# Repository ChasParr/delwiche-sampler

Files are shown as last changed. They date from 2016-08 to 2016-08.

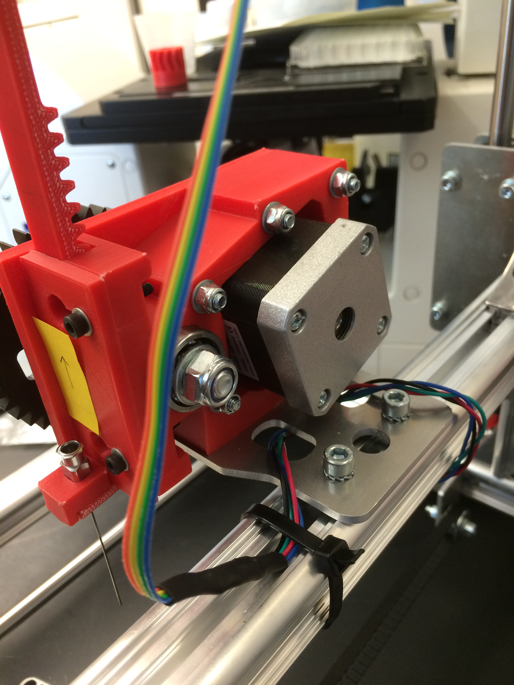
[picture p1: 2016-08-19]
pictures/IMG_1877.JPG

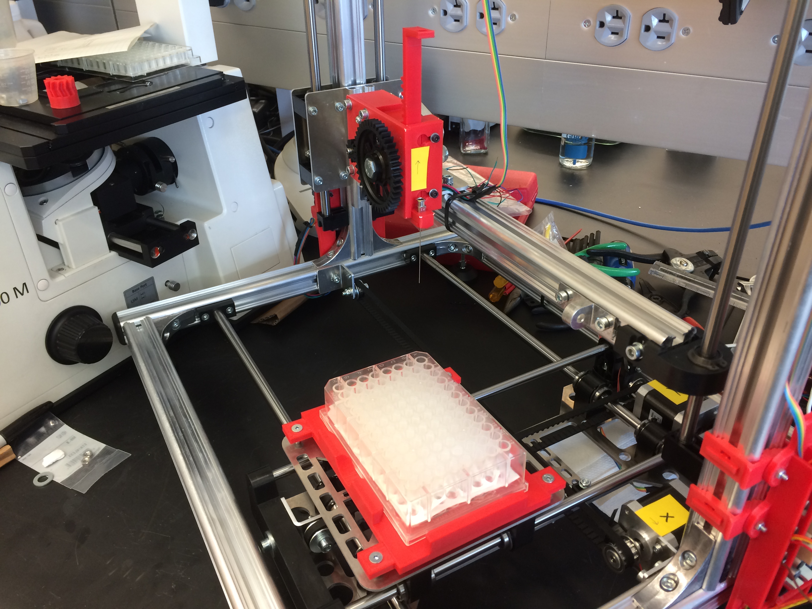
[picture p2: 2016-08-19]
pictures/IMG_1880[2].JPG

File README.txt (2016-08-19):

delwiche-sampler

This project converts a Velleman K8200 or 3Drag 3d printer into an autosampler.

Instructions for assembling the printer can be found here: http://www.k8200.eu/manual/building/
For this project do not assemble the coil support, heated bed, or extruder.

The parts used to replace the extruder can be 3d printed, the OpenSCAD files are in the "3D parts" folder.

Photos of the assembled extruder replacement can be found in the "pictures" folder.

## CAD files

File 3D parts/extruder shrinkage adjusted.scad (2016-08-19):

// Public Domain Parametric Involute Spur Gear (and involute helical gear and involute rack)
// version 1.1
// by Leemon Baird, 2011, Leemon@Leemon.com
//http://www.thingiverse.com/thing:5505

/*
this assemblage is intended to replace the extruder of a 
Velleman K8200 or 3Drag 3D printer.

most of the non-printable parts are the same, and used the same
as in the original extruder, except the following:
4x m3x12mm screws and washers (for attaching the motor)
2x m3x20mm bolts, washers, and nuts (for attaching the rack guide)
1x 8mmx60mm hex bolt (to replace the hobbed bolt)
*/

n1 = 12; //red gear number of teeth
n5 = 15;  //gray rack
mm_per_tooth = 5; //all meshing gears need the same mm_per_tooth (and the same pressure_angle)
pressure_angle=20;
thickness    = 6;   // 1/2 width of gear and rack
hole         = 8.2;   // center hole of gear
height       = 7.5;
angle        = 15;
animLength   = 11;
extensionBot = 30;
extensionTop = 30;
echo("outer radius: ", outer_radius(mm_per_tooth, n1));

d1  = pitch_radius(mm_per_tooth,n1);
rackOffset = mm_per_tooth / 3.1415926; 

// stand upright
rotate([0, -90, 0]){

// red gear
   
rotate([0,0, $t*360/n1 * animLength]){
    color([1.00,0.75,0.75]){
        gear(mm_per_tooth,n1,thickness,hole, angle, 0, pressure_angle);
        mirror([0, 0, 1])
            gear(mm_per_tooth,n1,thickness,hole, angle, 0, pressure_angle);
        render()
        translate([0, 0, -thickness - 9])
        difference(){
            cylinder(r = outer_radius(mm_per_tooth, n1), h = 9);
            cylinder(r = hole / 2, h = 9, $fn = 20);
            translate([0, 0, 4.5])
            rotate([90, 0, 0])
            cylinder(r = 1.5, h = outer_radius(mm_per_tooth, n1), $fn = 10);
        }
    }
}


// rack
translate([(-floor(n5/2)-floor(n1/2)+$t*animLength+n1/2-n5/2 + 2)*mm_per_tooth,-d1-0,0]){
    color([0.75,0.75,0.75]){
        rack(mm_per_tooth,n5,thickness,height, angle, pressure_angle);
        mirror([0, 0, 1])
            rack(mm_per_tooth,n5,thickness,height, angle, pressure_angle);
    }
    
    // bottom extension 
    translate([-extensionBot - mm_per_tooth/4, rackOffset - height, 0]){
        render() difference(){
            translate([0, 0, -thickness]){
                cube([extensionBot, height - rackOffset * 2, thickness * 2]); // shaft
                translate([0, -height * 1.5 - 5, 0])
                    cube([5, height * 1.5 + 5, thickness * 2]); // foot
            }
            translate([0, -height * .7 - 5, 0])
                rotate([0, 90, 0])
                    cylinder(h = 5, r = 3, $fn = 16);// hole
            
            translate([-1, -height * 1.5 - 5, -thickness - 1]){ // foot bevels
                // bottom
                rotate([0, -angle, 0])
                    cube([2.5, height * 2.5 + 5, thickness*1.2]);
                translate([0, 0, thickness * 2 + 2])
                    rotate([0, angle + 90, 0])
                        cube([thickness*1.2, height * 2.5 + 5, 2.5]);
                // top
                translate([6, 0, 0]){
                    rotate([0, -angle, 0])
                        cube([2.5, 8 * 1.5, (thickness+1)/cos(15)]);
                    translate([0, 0, thickness * 2 + 2])
                        rotate([0, angle + 90, 0])
                            cube([(thickness+1)/cos(15), 8*1.5, 2.5]);
                }
            }
        }
        // needle for reference
        //translate([25,-height * .7 - 5, 0])
            //needle();
    }
    
    // top extension
    translate([mm_per_tooth * n5 - mm_per_tooth / 4, rackOffset - height, 0]){
        translate([0, 0, -thickness])
            cube([extensionTop, height - rackOffset * 2, thickness * 2]); // shaft
        translate([extensionTop - 4, 0, 0]){
            render() difference(){
                translate([0, -height * 1.5 - 5, -thickness])
                    cube([4, height * 1.5 + 5, thickness * 2]); // foot
                translate([0, -height * .7 - 5, 0])
                    rotate([0, 90, 0])
                        cylinder(h = 5, r = 4);         // hole
            }
        }
    }
    
}

render(){
    translate([0, 0, 11.5 + .1])
        rotate([0, 180, -90]){
            translate([0, 0, -.1])
                newPlate();
            centerBlock();
            translate([-.1, 0, 0])
                rackGuide();
        }
}

}


// for printing
/*
render() newPlate();
translate([-28, -39, 0])
    cylinder(r = 7, h = 1);
translate([-28, 37, 0])
    cylinder(r = 7, h = 1);
translate([78, -39, 0])
    cylinder(r = 7, h = 1);
translate([78, 37, 0])
    cylinder(r = 7, h = 1);
*/
/*
render() rotate([0, 90, 0])
    translate([16, 0, 0])
        rackGuide();
translate([-2.3, -5, 0])
    cylinder(r = 3.5, h = 1, $fn = 20);
translate([-2.3, 4.2, 0])
    cylinder(r = 3.5, h = 1, $fn = 20);
translate([-2.3, -27.8, 0])
    cylinder(r = 3.5, h = 1, $fn = 20);
translate([-2.3, 27.2, 0])
    cylinder(r = 3.5, h = 1, $fn = 20);
translate([3, 35, 0])
    cylinder(r = 3.5, h = 1, $fn = 20);
translate([3, -37, 0])
    cylinder(r = 3.5, h = 1, $fn = 20);
translate([34.8, 35, 0])
    cylinder(r = 3.5, h = 1, $fn = 20);
translate([34.8, -37, 0])
    cylinder(r = 3.5, h = 1, $fn = 20);
*/
/*
render() translate([0, 0, 33])
    rotate([0, 180, 0])
        centerBlock();
translate([19, 35, 0])
    cylinder(r = 5, h = 1);
translate([19, -37, 0])
    cylinder(r = 5, h = 1);
translate([0, 35, 0])
    cylinder(r = 5, h = 1);
translate([-.5, -37, 0])
    cylinder(r = 5, h = 1);
translate([-30, 35, 0])
    cylinder(r = 5, h = 1);
translate([-35, -39, 0])
    cylinder(r = 5, h = 1);
translate([-77, 35, 0])
    cylinder(r = 5, h = 1);
translate([-77, -37, 0])
    cylinder(r = 5, h = 1);
*/
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

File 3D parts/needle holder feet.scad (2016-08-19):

thickness = 8;
angle = 15;
space = .4;
$fn = 17;

render() difference(){
    union(){
        cylinder(r = 2.85, h = thickness + 3);
        difference(){
            union(){
                translate([-6, -5.5, 0])
                    cube([12, 12.25, thickness]);
                translate([-6, 6.5, 0])
                    cube([12, 3, thickness + 3]);
            }
            translate([0, -5.75, thickness])
                rotate([0, angle, 0])
                    cube([12, 12.25, thickness]);
            translate([0, -5.75, thickness])
                rotate([0, -angle, 0])
                    translate([-12, 0, 0])
                        cube([12, 12.25, thickness]);
            translate([0, 6.5, thickness + 3])
                rotate([0, angle, 0])
                    cube([12, 3, thickness]);
            translate([0, 6.5, thickness + 3])
                rotate([0, -angle, 0])
                    translate([-12, 0, 0])
                        cube([12, 3, thickness]);
            
        }
        
    }
    
    cylinder(r = .3 + space, h = thickness + 3);
    difference(){
        intersection(){
            minkowski(){
            cube([3.8, 3, 9], true);
            cylinder(h = 1, r=1.5 + space);
            }
        }
    }
    translate([0, 0, 5]){
    cylinder(r1 = 2.3 + space, r2 = 1.5 + space, h = 2);
        translate([0, 0, 2]){
            cylinder(h = 1.1, r1 = 1.5 + space, r2 = 1.5 + space);
            translate([0, 0, 1.1]) 
                cylinder(h = 1.7, r1 = 1.5 + space, r2 = 1.1 + space);
            cylinder(h = 3, r1 = 1.1 + space, r2 = 1 + space);
        }
    }
}

//feet
translate([-8, -8, 0])
    cylinder(r = 4, h = 1);
translate([-8, 12, 0])
    cylinder(r = 4, h = 1);
translate([8, -8, 0])
    cylinder(r = 4, h = 1);
translate([8, 12, 0])
    cylinder(r = 4, h = 1);

//translate([0, 0, -8.])
//    rotate([0, 90, 0])
//        needle();

module needle(){
$fn = 20;
    rotate([0, -90, 0]){
        render() difference(){
            union(){
                translate([0, 0, .4])
                minkowski(){
                    cube([3.8, 3, .8], true);
                    cylinder(h = .1, r=1.5);
                }
                cylinder(h = 5, r=2.8);    
                translate([0, 0, 9]){
                    difference(){
                        intersection(){
                            minkowski(){
                            cube([3.8, 3, 10], true);
                                
                            cylinder(h = 1, r=1.5);
                            }
                            translate([0, 0, 2])
                            sphere(r = 7, $fn = 40);
                        }
                        translate([0, 0, 9]){
                            rotate_extrude(angle = 360){
                                translate([5.4, 0, 0])
                                    scale([.8, 1.1, 1])
                                        circle(r = 6, $fn = 40);
                            }
                        }
                    }
                }
                translate([0, 0, 15]){
                        cylinder(h = 1.1, r1 = 1.5, r2 = 1.5);
                        translate([0, 0, 1.1]) 
                            cylinder(h = 1.7, r1 = 1.5, r2 = 1.1);
                        cylinder(h = 3, r1 = 1.1, r2 = 1);
                    }
                //needle
                cylinder(h = 70, r = .3);
            }
            translate([-7, 0, 0]){
                cylinder(h = 15, r = 3.9, $fn = 40);
            }
            translate([7, 0, 0]){
                cylinder(h = 15, r = 3.9, $fn = 40);
            }
            cylinder(h = 7, r = 2.1);
            translate([0, 0, 7]){
                cylinder(h = 2, r1 = 2.1, r2 = .5);
                translate([0, 0, 2])
                    cylinder(h = 5, r1 = .5, r2 = .25);
            }
            cylinder(h = 70, r = .2);
        }
    }
}

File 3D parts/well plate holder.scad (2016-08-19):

$fn = 24;
// parameters (mm)

baseLength = 127.76;            // plate length
baseWidth = 85.48;              // plate width
room = .17;

length = baseLength + room*2;   // indentation length
width = baseWidth + room*2;     // indentation width
height = 10;                    // indentation height


// for specific max dimensions: 
// marginX = ([desiredLength] - length) / 2;
// marginY = ([desiredWidth] - width) / 2;
// marginZ = ([desiredHeight] - height);
marginX = 10;            // wall thickness (length)
marginY = 10;            // wall thickness (width)
marginZ = 6;             // base thickness (height)

// to remove a strut set it to 0
lipWidth = 10;          // lip width
strutA = 15;            // - strut width
strutB = 12;            // | strut width
strutX = 10;            // X struts width
strutZ = 5;             // strut thickness

screwMargin = 8;
screwRad = 2;
screwHeadRad = 4;
screwHeadDepth = 2;
screwDistX = 122;
screwDistY = 122;
plateThickness = 5;

// calculations
fullLength = length + marginX * 2;  // full length
fullWidth = width + marginY * 2;    // full width
fullHeight = height + marginZ;    // full height
cutoutLength = length - lipWidth * 2;  // cutout length
cutoutWidth = width - lipWidth * 2;    // cutout width
// diagonal strut length
strutLength = sqrt(cutoutLength*cutoutLength + cutoutWidth*cutoutWidth);
// screw plate dimensions
plateX = screwMargin * 2;
plateY = (screwMargin + (screwDistY - fullWidth) / 2);
offsetX = (screwMargin + (screwDistX - fullLength) / 2);


// Frame
translate([offsetX, plateY, 0]){
    // well plate (remove for printing)
    /*
    translate([marginX + room, marginY + room, marginZ]){
        cube([127.76, 85.48, 5.5]);
        translate([1.5, 1.5, 0]){
            cube([124.76, 82.48, 14.1]); 
        }
    }
    */
    render() difference(){
        // outside block
        cube([fullLength, fullWidth, fullHeight]);
        // indentation
        translate([marginX, marginY, marginZ]){
            cube([length, width, height]);
        }
        // corner cuts
        translate([0, 0, marginZ]){
            rotate([0, 0, 45]){
                translate([-10, -20, 0]){
                    cube([60, 30, height + 2]);
                }
            }
            cube([33.3, 19.2, height + 2]);
            translate([0, fullWidth, 0]){
                rotate([0, 0, -45]){
                    translate([-10, -10, 0]){
                        cube([60, 30, height + 2]);
                    }
                }
                translate([0, -19.2, 0])
                cube([33.3, 19.2, height + 2]);
            }
            translate([fullLength, fullWidth, 0]){
                rotate([0, 0, 225]){
                    translate([-10, -20, 0]){
                        cube([60, 30, height + 2]);
                    }
                }
                translate([-33.3, -19.2, 0])
                cube([33.3, 19.2, height + 2]);
            }
            translate([fullLength, 0, 0]){
                rotate([0, 0, -225]){
                    translate([-10, -10, 0]){
                        cube([60, 30, height + 2]);
                    }
                }
                translate([-33.3, 0, 0])
                cube([33.3, 19.2, height + 2]);
            }
        }
        // cutout bottom
        translate([marginX + lipWidth, marginY + lipWidth, 0]){
            cube([cutoutLength, cutoutWidth, marginZ]);
        }
        // side holes
        translate([fullLength / 2, 0, fullHeight + 2]){
            rotate([-90, 0, 0]){
            cylinder(h = marginY, r = height + 2);
            }
        }
        translate([fullLength / 2, fullWidth, fullHeight + 2]){
            rotate([90, 0, 0]){
            cylinder(h = marginY, r = height + 2);
            }
        }
        // Bevel
        translate([fullLength / 2, fullWidth / 2, fullHeight+ height/2]){
            intersection(){
                rotate([45, 0, 0]){
                    // along x
                    cube([fullLength, fullWidth/sqrt(2), fullWidth/sqrt(2)], true);
                }
                rotate([0, 45, 0]){
                    // along y
                    cube([fullLength/sqrt(2), fullWidth, fullLength/sqrt(2)], true);
                }
                cube([fullLength, fullWidth, height*2], true);
            }
        }
    }
    
    // Struts
    
    // strutA
    // [   ]
    // [---]
    // [   ].
    translate([(fullLength - strutA) / 2, marginY + lipWidth, 0]){
        cube([strutA, cutoutWidth, strutZ]);
    }

    // strutB
    // [ | ]
    // [ | ]
    // [ | ].
    translate([marginX + lipWidth, (fullWidth - strutB) / 2, 0]){
        cube([cutoutLength, strutB, strutZ]);
    }

    // strutX
    // [\  ]
    // [ \ ]
    // [  \].
    translate([(marginX + lipWidth), (marginY + lipWidth), 0]){
        rotate([0, 0, atan2(cutoutWidth, cutoutLength)]){
            translate([0, -strutX / 2, 0]){
                cube([strutLength, strutX, strutZ]);
            }
        }
    }

    // strutX
    // [  /]
    // [ / ]
    // [/  ].
    translate([(marginX + lipWidth), marginY + width - lipWidth, 0]){
        rotate([0, 0, atan2(-cutoutWidth, cutoutLength)]){
            translate([0, -strutX / 2, 0]){
                cube([strutLength, strutX, strutZ]);
            }
        }
    }
    translate([marginX + lipWidth + cutoutLength, marginY + lipWidth, 0]){
        rotate([0, 0, 45]){
            translate([-10, -10, 0]){
                cube([20,20,marginZ]);
            }
        }
    }
    translate([marginX + lipWidth + cutoutLength, marginY + lipWidth + cutoutWidth, 0]){
        rotate([0, 0, 45]){
            translate([-10, -10, 0]){
                cube([20,20,marginZ]);
            }
        }
    }
}

// Screw plates
render() difference(){
    cube([plateX, plateY, plateThickness]);
    translate([screwMargin, screwMargin, 0]){
        cylinder(h = plateThickness, r = screwRad);
        translate([0, 0, plateThickness - screwHeadDepth]){
            cylinder(h = screwHeadDepth, r1 = screwRad, r2 = screwHeadRad);
        }
    }
}
render() difference(){
    translate([screwDistX, 0, 0]){
        cube([plateX, plateY, plateThickness]);
    }
    translate([screwMargin + screwDistX, screwMargin, 0]){
       cylinder(h = plateThickness, r = screwRad);
       translate([0, 0, plateThickness - screwHeadDepth]){
            cylinder(h = screwHeadDepth, r1 = screwRad, r2 = screwHeadRad);
        }
    } 
}
render() difference(){
    translate([0, plateY + fullWidth, 0]){
        cube([plateX, plateY, plateThickness]);
    }
    translate([screwMargin, screwMargin + screwDistY, 0]){
       cylinder(h = plateThickness, r = screwRad);
       translate([0, 0, plateThickness - screwHeadDepth]){
            cylinder(h = screwHeadDepth, r1 = screwRad, r2 = screwHeadRad);
       }
    }
}
render() difference(){
    translate([screwDistX, plateY + fullWidth, 0]){
        cube([plateX, plateY, plateThickness]);
    }
    translate([screwMargin + screwDistX, screwMargin + screwDistY, 0]){
       cylinder(h = plateThickness, r = screwRad);
       translate([0, 0, plateThickness - screwHeadDepth]){
            cylinder(h = screwHeadDepth, r1 = screwRad, r2 = screwHeadRad);
       }
    }
}

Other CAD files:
3D parts/needle holder.scad

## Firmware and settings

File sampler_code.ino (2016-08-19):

/**
* G-code interpreter for the Delwiche-Sampler project
*   
* Copyright 2016 Chas Parr <cxp2265@rit.edu>
*
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
* Some of the following code is derived from the GcodeCNCDemo project
* http://www.github.com/MarginallyClever/GcodeCNCDemo
*/

/**
 * This sketch allows the sampler to interpret g-code commands sent to it via serial port.
 * 
 * In the Arduino IDE under 'tools' set the board to "Arduino/Genuino Mega or Mega 2560", 
 * and the port to whichever one the Arduino is connected to.
 * 
 * While uploading to the arduino, hold a screwdriver between the prongs on the port labeled "JPROG" 
 * until the upload is complete
 * 
 * The Serial Monitor tool in the IDE can be used to send G-code directly to the machine for testing purposes
 */

//------------------------------------------------------------
// Constants
//------------------------------------------------------------
#define BAUD            (57600)   // communication rate
#define MAX_BUF         (64)      // how long of a message can be stored
#define STEPS_PER_TURN  (200)     // the number of full steps for one revolution of a stepper motor
#define MICROSTEPS      (16)      // the number of microsteps each step is divided into
#define NUM_AXES        (4)       // the number of axes that can be moved along (X, Y, Z, E)
#define MAX_FEEDRATE    (1000000) // the highest speed (no delay between steps)
#define MIN_FEEDRATE    (1)

//------------------------------------------------------------
// Structs
//------------------------------------------------------------
/**
 * Motor struct
 * stores pin locations, motor/axis settings, and positional information
 */
typedef struct {
  int step_pin;       // this pin makes the motor step
  int dir_pin;        // this pin controls the motor direction
  int enable_pin;     // this pin enables the motor
  int switch_pin;     // this pin reads from an end stop if there is one, otherwise set it to -1
  float steps_per_mm; // the number of microsteps it takes to move the axis linearly one mm
  bool invert;        // flips the motor direction
  long pos;           // absolute position in microsteps
  long min_pos;       // minimum position on axis in microsteps (usually 0)
  long max_pos;       // maximum position on axis in microsteps
  int dir;            // set to 1 or -1 when moving, used to increment position
} Motor;

//------------------------------------------------------------
// Vars
//------------------------------------------------------------
Motor motors[NUM_AXES]; // stores the motors
char buffer[MAX_BUF];   // stores command till it hits a ';'
int sofar;              // position in buffer
boolean abs_mode;     
  // absolute mode (true): move commands are given as a position to move to
  // relative mode (false): move commands are given as a distance to move

boolean mm_mode;
  // (true): distances are read as millimeters
  // (false): distances are read as micro steps

// speeds
long fr = 0;            // feed rate
long step_delay;        // the delay between steps, derived from the feed rate

//------------------------------------------------------------
// Methods
//------------------------------------------------------------
/**
 * Set the feedrate (speed motors will move)
 * @input nfr the new speed in steps/second
 */
void set_feedrate(long nfr) {
  if(fr == nfr) return;  // quit if no change

  if(nfr > MAX_FEEDRATE || nfr < MIN_FEEDRATE) {  // don't allow crazy feed rates
    Serial.print(F("New feedrate must be greater than "));
    Serial.print(MIN_FEEDRATE);
    Serial.print(F("steps/s and less than "));
    Serial.print(MAX_FEEDRATE);
    Serial.println(F("steps/s."));
    return;
  }
  step_delay = MAX_FEEDRATE / nfr;  // calculate the delay between steps
  fr = nfr;
}

/**
 * provide positional information
 */
void where() {
  Serial.print("X ");
  Serial.print(motors[0].pos / motors[0].steps_per_mm);
  Serial.print("mm ");
  Serial.print(motors[0].pos);
  Serial.println(" micro steps");
  Serial.print("Y ");
  Serial.print(motors[1].pos / motors[1].steps_per_mm);
  Serial.print("mm ");
  Serial.print(motors[1].pos);
  Serial.println(" micro steps");
  Serial.print("Z ");
  Serial.print(motors[2].pos / motors[2].steps_per_mm);
  Serial.print("mm ");
  Serial.print(motors[2].pos);
  Serial.println(" micro steps");
  Serial.print("E ");
  Serial.print(motors[3].pos / motors[3].steps_per_mm);
  Serial.print("mm ");
  Serial.print(motors[3].pos);
  Serial.println(" micro steps");
  Serial.print("F ");
  Serial.println(fr);
}

/**
 * print helpful info
 */
void help() {
  Serial.println(F("Commands:"));
  Serial.println(F("G00 [X/Y/Z/E(steps or mm)] [F(steps/sec)]; - rapid move"));
  Serial.println(F("G21; - set units to mm"));  
  Serial.println(F("G24; - set units to micro steps"));  
  Serial.println(F("G28; - zero position"));  
  Serial.println(F("G90; - absolute mode"));
  Serial.println(F("G91; - relative mode"));
  Serial.println(F("M17; - enable motors"));
  Serial.println(F("M18; - disable motors"));
  Serial.println(F("M100; - this help message"));
  Serial.println(F("M114; - report position and feedrate"));
  
}

/**
 * set up the motor pins and settings
 */
void motor_setup() {
  // x-axis
  motors[0].step_pin = 54;
  motors[0].dir_pin = 55;
  motors[0].enable_pin = 38;
  motors[0].switch_pin = 3;
  motors[0].steps_per_mm = STEPS_PER_TURN * MICROSTEPS / 50;  // one full revolution moves 50mm
  motors[0].pos = 1;  // ensures it can zero on startup
  motors[0].min_pos = 0;
  motors[0].max_pos = 220 * motors[0].steps_per_mm; // max position is 220mm from zero
  motors[0].invert = true;

  // y-axis
  motors[1].step_pin = 60;
  motors[1].dir_pin = 61;
  motors[1].enable_pin = 56;
  motors[1].switch_pin = 14;
  motors[1].steps_per_mm = STEPS_PER_TURN * MICROSTEPS / 50;  // one full revolution moves 50mm
  motors[1].pos = 1;  // ensures it can zero on startup
  motors[1].min_pos = 0;
  motors[1].max_pos = 200 * motors[1].steps_per_mm; // max position is 200mm from zero
  motors[1].invert = false;

  // z-axis
  motors[2].step_pin = 46;
  motors[2].dir_pin = 48;
  motors[2].enable_pin = 63;
  motors[2].switch_pin = 18;
  motors[2].steps_per_mm = STEPS_PER_TURN * MICROSTEPS / 1.2;  // one full revolution moves 1.2mm
  motors[2].pos = 1;  // ensures it can zero on startup
  motors[2].min_pos = 0;
  motors[2].max_pos = 200 * motors[2].steps_per_mm; // max position is 200mm from zero
  motors[2].invert = false;

  // extruder
  motors[3].step_pin = 26;
  motors[3].dir_pin = 28;
  motors[3].enable_pin = 24;
  motors[3].switch_pin = -1;
  motors[3].steps_per_mm = STEPS_PER_TURN * MICROSTEPS / 14;  // one full revolution moves 14mm
  motors[3].pos = 0;  // prevent it from trying to zero on startup
  motors[3].min_pos = 0;
  motors[3].max_pos = 57 * motors[3].steps_per_mm; // max position is 57mm from zero
  motors[3].invert = true;

  for(int i = 0; i < NUM_AXES; i++) {  
    
    // set up the motor pins
    pinMode(motors[i].step_pin, OUTPUT);
    pinMode(motors[i].dir_pin, OUTPUT);
    pinMode(motors[i].enable_pin, OUTPUT);
    
    // set up the switch pin if there is an endstop
    if (motors[i].switch_pin > 0){
      pinMode(motors[i].switch_pin, INPUT_PULLUP);
    }
  }
}

/**
 * prepare for the next command
 */
void ready() {
  sofar = 0;
  Serial.print(F("> "));
}

/**
 * Look for character /code/ in the buffer and read the float that immediately follows it.
 * @return the value found.  If nothing is found, /val/ is returned.
 * @input code the character to look for.
 * @input val the return value if /code/ is not found.
 */
float parseNumber(char code, float val) {
  char *ptr = buffer;
  while(ptr && *ptr && ptr < buffer + sofar) {
    if(*ptr == code) {
      return atof(ptr + 1);
    }
    ptr = strchr(ptr, ' ') + 1;
  }
  return val;
}

/**
 * Read the input buffer and find any recognized commands.  One G or M command per line.
 */
void processCommand() {
  int cmd = parseNumber('G', -1);
  switch(cmd) {
    case 0:  // rapid move command
      set_feedrate(parseNumber('F', fr));
      
      // read positions into rapid_move
      // if a position is unspecified it defaults to no movement
      // in mm mode the input is multiplied by 100 to preserve decimals
      if (!abs_mode){
        if (mm_mode){
          rapid_move( parseNumber('X', 0) * 100,
                      parseNumber('Y', 0) * 100,
                      parseNumber('Z', 0) * 100,
                      parseNumber('E', 0) * 100);
        } else{
          rapid_move( parseNumber('X', 0),
                      parseNumber('Y', 0),
                      parseNumber('Z', 0),
                      parseNumber('E', 0) );
        }
      } else {
        if (mm_mode){
          rapid_move( parseNumber('X', motors[0].pos / motors[0].steps_per_mm) * 100,
                      parseNumber('Y', motors[1].pos / motors[1].steps_per_mm) * 100,
                      parseNumber('Z', motors[2].pos / motors[2].steps_per_mm) * 100,
                      parseNumber('E', motors[3].pos / motors[3].steps_per_mm) * 100);
          
        } else{
          rapid_move( parseNumber('X', motors[0].pos),
                      parseNumber('Y', motors[1].pos),
                      parseNumber('Z', motors[2].pos),
                      parseNumber('E', motors[3].pos) );
        }
      }
      break;
    case 21:  // set units to mm
      mm_mode = true;
      Serial.println("input set to mm"); 
      break;
    case 24:  // set units to micro steps
      mm_mode = false;
      Serial.println("input set to micro steps"); 
      break;
    case 28:  // zero position
      zero_position();
      break;
    case 90:  // set to absolute mode
      abs_mode = true;
      Serial.println("mode set to absolute, enter positions to move to them"); 
      break;
    case 91:  // set to relative mode
      abs_mode = false;
      Serial.println("mode set to relative, enter distances to move"); 
      break;
    default: break;
    }
  
  cmd = parseNumber('M',-1);
  switch(cmd) {
    case  17:  motor_enable();  break;
    case  18:  motor_disable();  break;
    case 100:  help();  break;
    case 114:  where(); break;
    default:  break;
  }
}

/**
 * enable all motors
 */
void motor_enable() {
  for(int i = 0 ; i < NUM_AXES; i++) {  
    digitalWrite(motors[i].enable_pin,LOW);
  }
}

/**
 * disable all motors
 */
void motor_disable() {
  for(int i = 0 ; i < NUM_AXES; i++) {  
    digitalWrite(motors[i].enable_pin,HIGH);
  }
}

/**
 * reposition without linear interpolation
 * @input newX the new x position (abs mode) or the distance to move along the x axis (rel mode)
 * @input newY the new y position (abs mode) or the distance to move along the y axis (rel mode)
 * @input newZ the new z position (abs mode) or the distance to move along the z axis (rel mode)
 * @input newE the new e position (abs mode) or the distance to move along the e axis (rel mode)
 * if in mm mode, the inputs are expected to be multiplied by 100 to preserve decimal places
 */
void rapid_move(long newX, long newY, long newZ, long newE) {
  
  // store new positions
  long new_pos[NUM_AXES];
  new_pos[0] = newX;
  new_pos[1] = newY;
  new_pos[2] = newZ;
  new_pos[3] = newE;

  // if in mm mode, convert the input (mm to move * 100) into microsteps
  if (mm_mode){
    for(int i = 0; i < NUM_AXES; i++){
      new_pos[i] *= (motors[i].steps_per_mm / 100);
    }
  }
  
  // add curent positions if in relative mode
  if (!abs_mode) {
    for(int i = 0; i < NUM_AXES; i++){
      new_pos[i] += motors[i].pos;
    }
  }
  
  
  for(int i = 0; i < NUM_AXES; i++){
    
    // check position validity and prevent illegal moves
    if (new_pos[i] > motors[i].max_pos){
      Serial.println("Move out of bounds, position now set to max");
      new_pos[i] = motors[i].max_pos;
    } else if (new_pos[i] < motors[i].min_pos){
      Serial.println("Move out of bounds, position now set to min");
      new_pos[i] = motors[i].min_pos;
    }
    
    // set direction
    if (new_pos[i] > motors[i].pos){
      motors[i].dir = 1;
      if (motors[i].invert){
        digitalWrite(motors[i].dir_pin, LOW);
      } else{
        digitalWrite(motors[i].dir_pin, HIGH);
      }
    } else{
      motors[i].dir = -1;
      if (motors[i].invert){
        digitalWrite(motors[i].dir_pin, HIGH);
      } else{
        digitalWrite(motors[i].dir_pin, LOW);
      }
    }
  }

  int check;
  do {                                    // loop until all motors have finished moving
    check = 0;
    for(int i = 0; i < NUM_AXES; i++){      // loop through motors
      if (motors[i].pos != new_pos[i]){       // check if motor in correct position
        digitalWrite(motors[i].step_pin, HIGH); // step motor
        digitalWrite(motors[i].step_pin, LOW);
        check++;                                // indicate that a move was made
        motors[i].pos += motors[i].dir;         // update position
      }
    }
    delayMicroseconds(step_delay);          // delay to control speed
  } while(check != 0);                    // check if any moves were made
  where();                                // report position
}

/**
 * move to endstops, 
 */
void zero_position(){
  
  // set direction
  for (int i = 0; i < NUM_AXES; i++){
    if (motors[i].invert){
      digitalWrite(motors[i].dir_pin, HIGH);
    } else{
      digitalWrite(motors[i].dir_pin, LOW);
    }
  }


  int check;
  do {
    check = 0;                                // loop until all axes are at zero
    for(int i = 0; i < NUM_AXES; i++) {         // loop through motors
      if(motors[i].pos > 0){                      // only move if not already at zero
        if (motors[i].switch_pin > 0){              // check if there is a switch
          if (digitalRead(motors[i].switch_pin)){     // check if switch is triggered
            motors[i].pos = 0;                          // set position to zero 
          } else{                                     // otherwise
            digitalWrite(motors[i].step_pin, HIGH);     // step motor
            digitalWrite(motors[i].step_pin, LOW);
          }
        } else {                                    // if there is no switch, just reset the position to what it thinks is zero
          digitalWrite(motors[i].step_pin, HIGH);
          digitalWrite(motors[i].step_pin, LOW);
          motors[i].pos--;
        }
        check++;                                  // indicate that a move was made
      }
    }
    delayMicroseconds(step_delay);              // delay to control speed
  } while(check != 0);                        // check if any moves were made
  where();                                    // report position
}

/**
 * runs once on startup
 */
void setup() {
  Serial.begin(BAUD);
  
  motor_setup();
  motor_disable();  // motors should be turned on when the control software is run
  
  help();
  //zero_position();
  set_feedrate(1000);
  abs_mode = true;
  mm_mode = true;
  ready();
}

/**
 * loops forever
 */
void loop() {
  while( Serial.available() > 0) {  // if something is there
    char c = Serial.read();           // get it 
    Serial.print(c);                  // repeat it back
    if(sofar < MAX_BUF - 1) {         // check if there is room in the buffer
      buffer[sofar++] = c;              // store it
    }
    if(c == '\n') {                   // check if the line ends
      Serial.print(F("\r\n"));          // display a line end
      buffer[sofar] = 0;                // end the buffer
      processCommand();                 // perform the command
      ready();                          // prepare to recieve the next command
    }
  }
}

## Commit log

2016-08-15 add sampler code
2016-08-19 change motors to disabled by default
2016-08-19 add 3d models of parts
    [extruder shrinkage adjusted.scad, needle holder feet.scad, needle holder.scad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]
2016-08-19 add pictures of assembled extruder replacement
2016-08-19 reorganize and add description to extruder replacement
    [extruder shrinkage adjusted.scad]

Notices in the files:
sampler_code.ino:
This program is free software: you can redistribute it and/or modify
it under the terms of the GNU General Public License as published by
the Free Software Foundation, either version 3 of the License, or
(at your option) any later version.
